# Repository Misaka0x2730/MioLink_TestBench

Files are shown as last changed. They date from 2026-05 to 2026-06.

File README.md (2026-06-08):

# MioLink TestBench

A hardware-in-the-loop bench for automated testing of the
[MioLink](https://github.com/Misaka0x2730/MioLink) debug probe.

The bench builds probe firmware and target test firmware, flashes both onto
real hardware, and runs a suite of functional tests over the physically wired
interfaces (SWD/JTAG, UART, RTT, SWO).

## How it works

A full run consists of three phases orchestrated by [`bench_run_all.sh`](scripts/bench_run_all.sh):

1. **Build probe firmware** ([`miolink_build_all.sh`](scripts/miolink_build_all.sh)) — builds
   every MioLink variant listed in the bench config and stages the `.uf2` images.
2. **Build target firmware** ([`targets_build_all.sh`](scripts/targets_build_all.sh)) —
   builds the `test_board` fixtures for each target platform and CLI backend.
3. **Run tests** ([`bench_run_tests_only.sh`](scripts/bench_run_tests_only.sh)) — flashes the
   probes and targets, verifies probe identity, and runs the tests.

Each script can also be run on its own if you only need a single phase.

## Bench configuration

The physical layout is described by a YAML file under [`config/`](config/): a
flat list of slots where each probe ↔ target pair carries everything needed —
probe serial number, target model, platform, wired interfaces, Vtref mode, SWO
presence, the set of CLI backends, and so on. Every field is documented inline
in the file.

A bench is fully described by its config, so you can keep one per physical setup
and select it with `--config` (the scripts default to
[`config/bench_pizero2w.yaml`](config/bench_pizero2w.yaml)).

## Repository layout

| Directory | Purpose |
|---|---|
| [`firmware/`](firmware/) | Test target firmware (`test_board`); platforms: `stm32f030`, `stm32f103`, `stm32f401`, `hc32f460` |
| [`scripts/cmake/`](scripts/cmake/) | Project-agnostic CMake build driver |
| [`scripts/miolink/`](scripts/miolink/) | Build, flash, and discovery of the MioLink probe (DFU detach / picotool) |
| [`scripts/usbutil/`](scripts/usbutil/) | Generic USB device lookup by VID/PID/serial |
| [`scripts/targets/`](scripts/targets/) | Target firmware builds and target control over GDB/BMP (`gdb`) |
| [`scripts/bench/`](scripts/bench/) | Bench runner and config parser |
| [`scripts/tests/`](scripts/tests/) | Functional tests: `uart`, `rtt`, `swo`, `buffer` |
| [`scripts/runner/`](scripts/runner/) | Self-hosted CI runner provisioning |
| `scripts/*.sh` | Entry-point wrappers from `scripts/`: `bench_run_all`, `bench_run_tests_only`, `miolink_build_all`, `targets_build_all` |
| [`hardware/`](hardware/) | KiCad adapter boards for WeAct Core Boards (STM32F1/F4, MSPM0G3507, STM32G0/C0) |
| [`config/`](config/) | Bench description YAMLs |

## Target platforms

The `test_board` firmware is built for several MCUs that cover different
Cortex-M cores: STM32F030 (CM0), STM32F103 (CM3), STM32F401 (CM4),
HC32F460 (CM4). Variants differ by CLI backend (UART / RTT / disabled),
SWO presence, and build type (Debug / Release).

## Getting started

### Prerequisites

- **ARM GNU Toolchain, CMake, Ninja** — for building the firmware (not needed on
  a bench host that only flashes and tests).
- **Python 3** with the packages from
  [`scripts/requirements.txt`](scripts/requirements.txt) (`pyusb`, `pygdbmi`,
  `pyserial`, `PyYAML`).
- **Git submodules** from [`.gitmodules`](.gitmodules) (CMSIS, STM32 HAL drivers,
  SEGGER RTT, embedded-cli) — pulled in by the clone step below.

### Setup

Clone the repository with its submodules:

```bash
git clone --recurse-submodules https://github.com/Misaka0x2730/MioLink_TestBench.git
cd MioLink_TestBench
```

If you already cloned without `--recurse-submodules`:

```bash
git submodule update --init --recursive
```

Install the Python dependencies:

```bash
pip install -r scripts/requirements.txt
```

## Usage

Run scripts from the repository root.

**Full run** — build probe firmware, build target firmware, flash, and test:

```bash
./scripts/bench_run_all.sh --miolink-firmware-root /path/to/MioLink/firmware
```

**Build only** — skip the flash-and-test phase:

```bash
./scripts/bench_run_all.sh --miolink-firmware-root /path/to/MioLink/firmware --build-only
```

**Run only** — reuse already-built images, just flash and test:

```bash
./scripts/bench_run_all.sh --run-only
```

**Individual phases:**

```bash
# 1. Build the MioLink probe .uf2 images
./scripts/miolink_build_all.sh --miolink-firmware-root /path/to/MioLink/firmware

# 2. Build the test_board target firmware
./scripts/targets_build_all.sh

# 3. Flash everything and run the tests
./scripts/bench_run_tests_only.sh
```

**Useful options** (anything after `--` is forwarded to the bench runner):

```bash
# Run a single probe by serial number
./scripts/bench_run_tests_only.sh -- --probe E66394664F387030

# Include slots marked enabled: false in the config
./scripts/bench_run_tests_only.sh -- --include-disabled

# Skip re-flashing the target firmware
./scripts/bench_run_tests_only.sh -- --no-target-flash

# Use a custom bench config
./scripts/bench_run_all.sh --config config/bench_pizero2w.yaml --miolink-firmware-root /path/to/MioLink/firmware
```

Pass `-h` / `--help` to any script for the full list of flags.

## CI/CD

There are two GitHub Actions workflows: one that purely builds the target
firmware, and one that runs the full hardware-in-the-loop bench.

### Build Test Firmware CI

[`build-test-firmware-ci.yml`](.github/workflows/build-test-firmware-ci.yml)
runs on every push and pull request to `main` (and on manual
`workflow_dispatch`). It compiles the `test_board` firmware for the **full
variant matrix** and packages the results, acting as a compile-only smoke test
that nothing has broken across platforms/configs.

- **`version` job** — derives one version string shared by every artifact name
  (git tag name for tag refs, otherwise the short SHA) so the build matrix and
  the packaging job stay consistent.
- **`build` job (matrix)** — a matrix over the variant axes: target platform,
  `CONFIG_CLI` (`UART` / `RTT` / `NONE`), `CONFIG_TEST_SWO` (`OFF` / `ON`), and
  build type (`Debug` / `Release`). Combinations a platform can't support are
  excluded (e.g. SWO on a Cortex-M0 with no ITM/TPIU). `fail-fast` is off, so one
  broken variant doesn't hide the rest. Each cell checks out submodules, sets up
  the ARM GCC toolchain, extracts any committed vendor SDK the platform needs,
  runs `cmake` configure + build, and uploads a version-stamped `.elf` artifact.
- **`package` job** — runs only if **all** matrix builds succeeded (so the
  archive is never silently incomplete), merges every per-variant ELF into a
  single `MioLink_TestBench_firmware_<version>` archive, and best-effort prunes
  the intermediate `elf-*` staging artifacts.

### Run Bench CI

[`run-bench-ci.yml`](.github/workflows/run-bench-ci.yml) runs the actual bench
on physical hardware. It is triggered by **`repository_dispatch`
(`miolink-build`)** from the MioLink build pipeline once that pipeline has built
the probe firmware — or manually via `workflow_dispatch` with a `run_id` (and an
optional `sha` to report on).

The flow is split so the physical bench host stays cheap (it never compiles):

1. **`build-fixtures` job** (GitHub-hosted) — builds the `test_board` fixtures
   in the exact layout `run_bench.py` expects
   (`firmware/build/cli-X_swo-Y/test_boards/...`) and uploads only the `.elf`
   files as a `target-fixtures` artifact. The self-hosted runner therefore never
   needs a toolchain.
2. **`bench` job** (self-hosted, labels `[self-hosted, miolink-bench]`) — the
   one with the real hardware (e.g. a Pi Zero 2W):
   - Resolves the MioLink `run_id` from the dispatch payload or manual input.
   - **Cross-repo downloads** the exact probe `.uf2` set that this MioLink run
     produced (`actions/download-artifact` with `repository: Misaka0x2730/MioLink`
     + `run-id`, authenticated with the `MIOLINK_BENCH_TOKEN` secret). This
     guarantees the bench tests the precise artifacts that triggered it.
   - Downloads and unpacks the `target-fixtures` from step 1, installs the
     runtime-only Python deps, and runs `scripts/bench_run_tests_only.sh` to
     flash and test against the bench config.
   - A `concurrency` group (`cancel-in-progress: false`) serializes runs so
     concurrent MioLink changes **queue** instead of fighting over the single
     physical bench.
3. **`report` job** — `if: always()`, so it runs even when the bench fails or is
   skipped. It posts a commit status (`context: miolink-bench`) back onto the
   MioLink commit SHA, which renders in MioLink's PR checks list and resolves the
   pending status MioLink had set. It no-ops when there is no SHA to report on
   (e.g. a manual run without the `sha` input).

Both the cross-repo artifact download and the status report authenticate with
the **`MIOLINK_BENCH_TOKEN`** repository secret — a token with read access to
the MioLink repo's Actions artifacts and write access to its commit statuses.
The workflow cannot fetch the probe firmware or report results without it.

In other words, the two repos form a loop: **MioLink builds probe firmware →
dispatches to this repo → the bench flashes and tests it on real targets →
the result is reported back as a check on the MioLink commit.**

### Self-hosted bench runner

The `bench` job lands on a self-hosted runner labelled
`[self-hosted, miolink-bench]` — the host physically wired to the probes and
targets. Because compilation happens on GitHub-hosted runners, this host only
flashes and tests, so a low-powered SBC (e.g. a Raspberry Pi / Pi Zero 2W
running DietPi) is enough.

[`scripts/runner/provision_ghrunner.sh`](scripts/runner/provision_ghrunner.sh)
provisions such a host from scratch. It installs exactly what
`scripts/bench/run_bench.py` needs at job time — `arm-none-eabi-gdb` (flashes
targets over the BMP GDB/MI server), `picotool` (BOOTSEL flashing of RP2 probes,
incl. RP2350 / Pico 2W), `dfu-util` (detaches a running probe into BOOTSEL), and
`python3` + libusb for the runtime deps — plus udev rules and group membership
so an unprivileged service user gets raw-USB and `/dev/ttyACM*` access. It then
registers the GitHub Actions runner under a dedicated `ghrunner` user and
installs it as an auto-starting systemd service.

Run it on the Pi (it re-execs itself with `sudo`):

```bash
sudo ./scripts/runner/provision_ghrunner.sh \
    --toolchain-url <ARM_GNU_TOOLCHAIN_TARBALL_URL> \
    --token         <GITHUB_RUNNER_REGISTRATION_TOKEN> \
    --labels        miolink-bench \
    --url           https://github.com/Misaka0x2730/MioLink_TestBench
```

The `--labels` value must include `miolink-bench` so the `bench` job targets
this host.

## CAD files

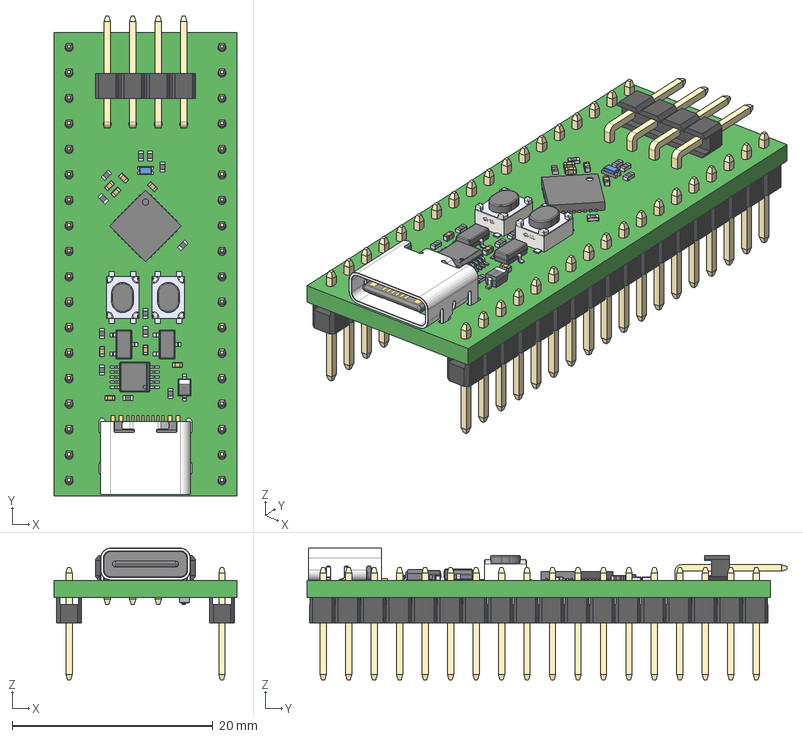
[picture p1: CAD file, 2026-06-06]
hardware/WeAct_MSPM0G3507_CoreBoardAdapter/WeAct-MSPM0G3507SRHBCoreBoard_V10 3D.step
18.2 x 47.8 x 13.1 mm
Leader x 16
Thermal_Shape
SOLID^SW-SMD_4P-L4.2-W3.3-P2.15-LS5.1_SW1_3D_PCB1_2023-06-10(2)_3D_ PCB1_2023-06-10 x 2
R0603
Extruded
Mid_Body x 12
Mark x 12
pin_header_aw140-ea-g04g
pin_header_aw140-eg-g18d x 2
USB_Type-C_A
User Library-SOD323
User Library-led_0603LED0603 blue

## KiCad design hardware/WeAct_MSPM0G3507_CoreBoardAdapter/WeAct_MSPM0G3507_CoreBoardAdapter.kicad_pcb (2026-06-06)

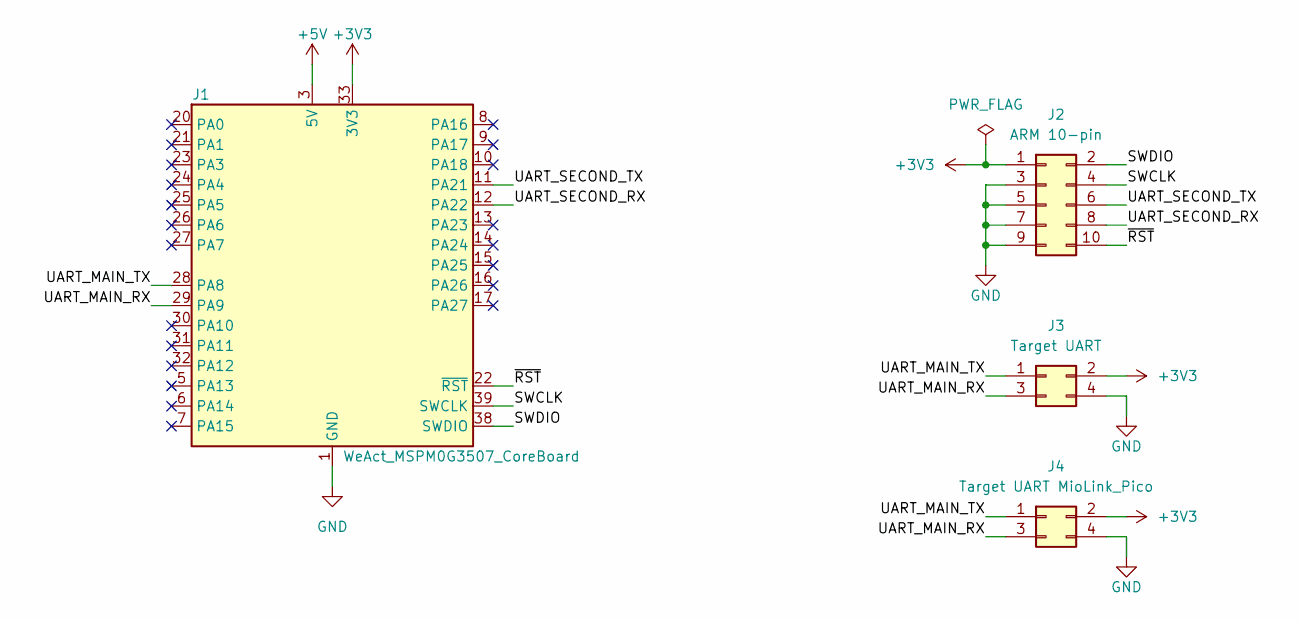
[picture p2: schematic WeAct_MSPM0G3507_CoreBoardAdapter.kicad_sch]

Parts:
J1: WeAct_MSPM0G3507_CoreBoard
J2: ARM 10-pin; PinSocket_2x05_P2.54mm_Horizontal
J3: Target UART; PinSocket_2x02_P2.54mm_Horizontal
J4: Target UART MioLink_Pico; PinSocket_2x02_P2.54mm_Horizontal

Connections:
+3V3: J1.33 (3V3), J1.34 (3V3), J1.37 (3V3), J2.1, J3.2, J4.2
+5V: J1.3 (5V), J1.4 (5V)
/SWCLK: J1.39 (SWCLK), J2.4
/SWDIO: J1.38 (SWDIO), J2.2
/UART_MAIN_RX: J1.29 (PA9), J3.3, J4.3
/UART_MAIN_TX: J1.28 (PA8), J3.1, J4.1
/UART_SECOND_RX: J1.12 (PA22), J2.8
/UART_SECOND_TX: J1.11 (PA21), J2.6
/~RST: J1.22 (~RST), J2.10
GND: J1.1 (GND), J1.2 (GND), J1.18 (GND), J1.19 (GND), J1.35 (GND), J1.36 (GND), J1.40 (GND), J2.3, J2.5, J2.7, J2.9, J3.4, J4.4

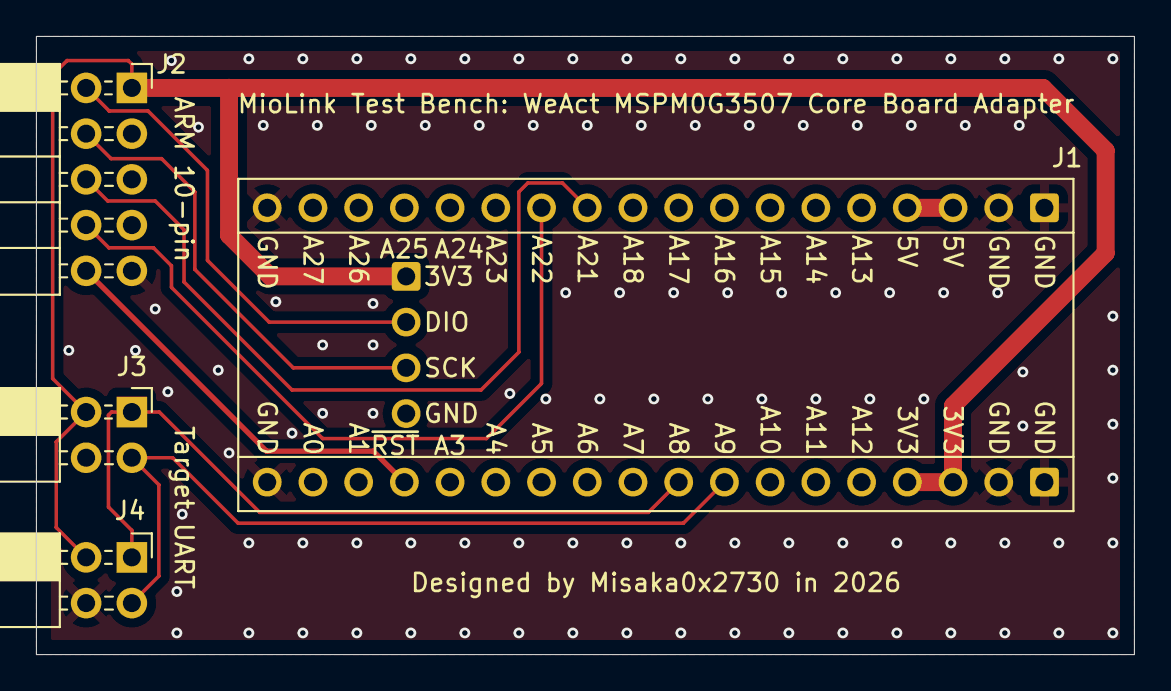
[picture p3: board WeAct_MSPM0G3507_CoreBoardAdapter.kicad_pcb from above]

Board: 2 copper layers, 61.0 x 34.3 mm, 5 parts (1 on the bottom side), 10 nets.

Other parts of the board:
G1: PROJECT PAGE; LOGO

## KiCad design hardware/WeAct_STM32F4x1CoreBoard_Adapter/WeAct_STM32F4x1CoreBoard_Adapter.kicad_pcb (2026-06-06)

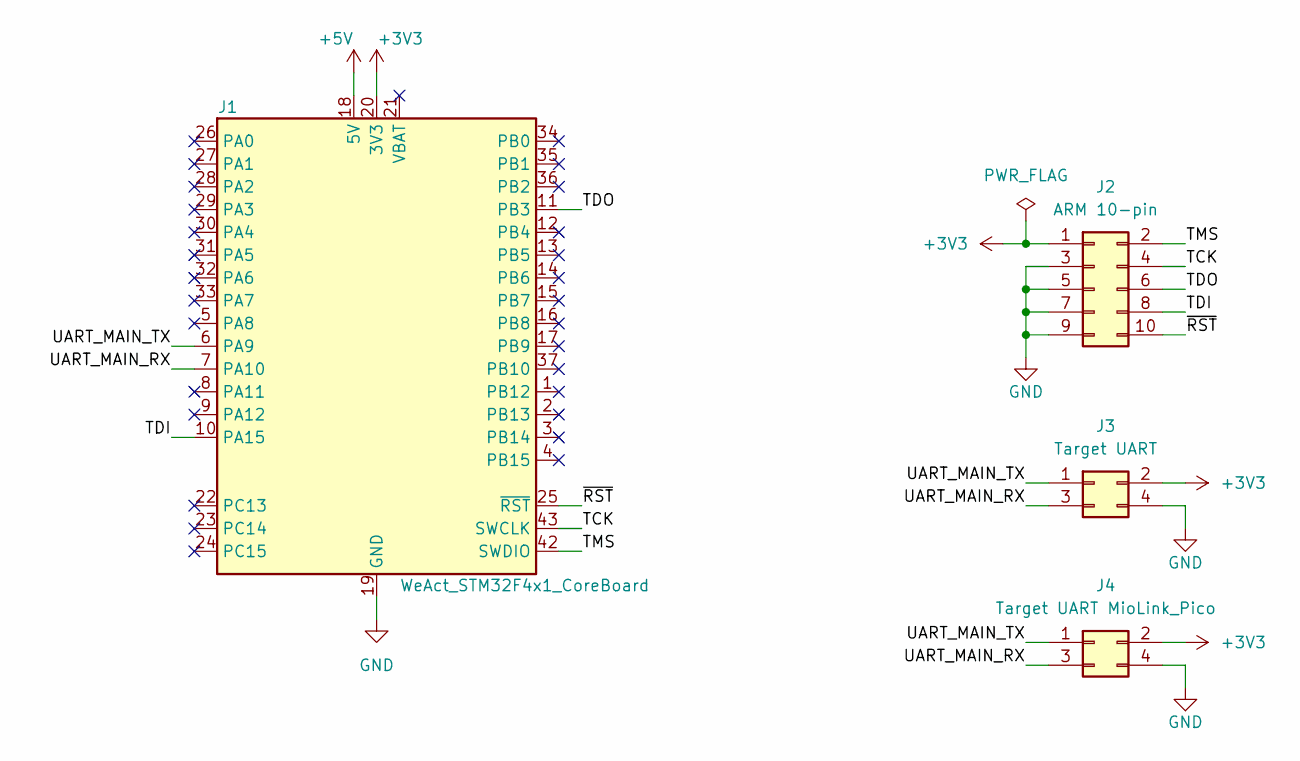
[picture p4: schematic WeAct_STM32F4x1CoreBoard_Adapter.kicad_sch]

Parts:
J1: WeAct_STM32F4x1_CoreBoard
J2: ARM 10-pin; PinSocket_2x05_P2.54mm_Horizontal
J3: Target UART; PinSocket_2x02_P2.54mm_Horizontal
J4: Target UART MioLink_Pico; PinSocket_2x02_P2.54mm_Horizontal

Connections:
+3V3: J1.20 (3V3), J1.38 (3V3), J1.41 (3V3), J2.1, J3.2, J4.2
+5V: J1.18 (5V), J1.40 (5V)
/TCK: J1.43 (SWCLK), J2.4
/TDI: J1.10 (PA15), J2.8
/TDO: J1.11 (PB3), J2.6
/TMS: J1.42 (SWDIO), J2.2
/UART_MAIN_RX: J1.7 (PA10), J3.3, J4.3
/UART_MAIN_TX: J1.6 (PA9), J3.1, J4.1
/~RST: J1.25 (~RST), J2.10
GND: J1.19 (GND), J1.39 (GND), J1.44 (GND), J2.3, J2.5, J2.7, J2.9, J3.4, J4.4

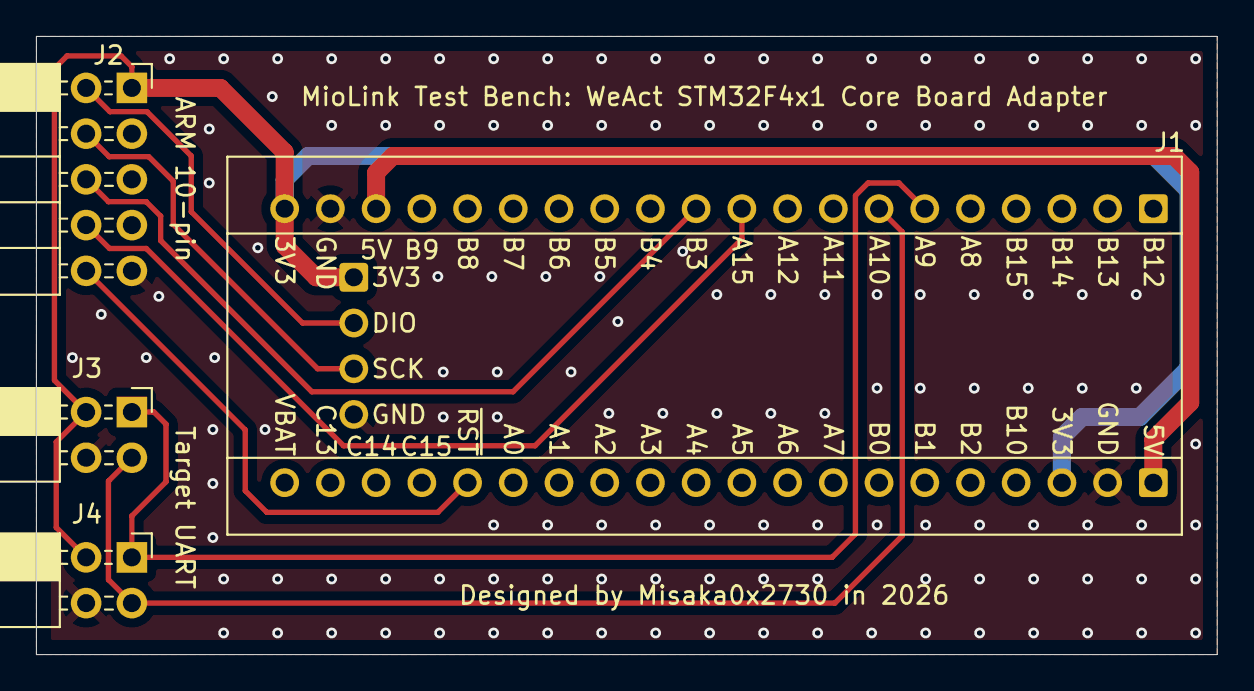
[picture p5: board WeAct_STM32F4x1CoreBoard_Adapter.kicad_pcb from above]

Board: 2 copper layers, 65.6 x 34.3 mm, 5 parts (1 on the bottom side), 10 nets.

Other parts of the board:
G1: PROJECT PAGE; LOGO

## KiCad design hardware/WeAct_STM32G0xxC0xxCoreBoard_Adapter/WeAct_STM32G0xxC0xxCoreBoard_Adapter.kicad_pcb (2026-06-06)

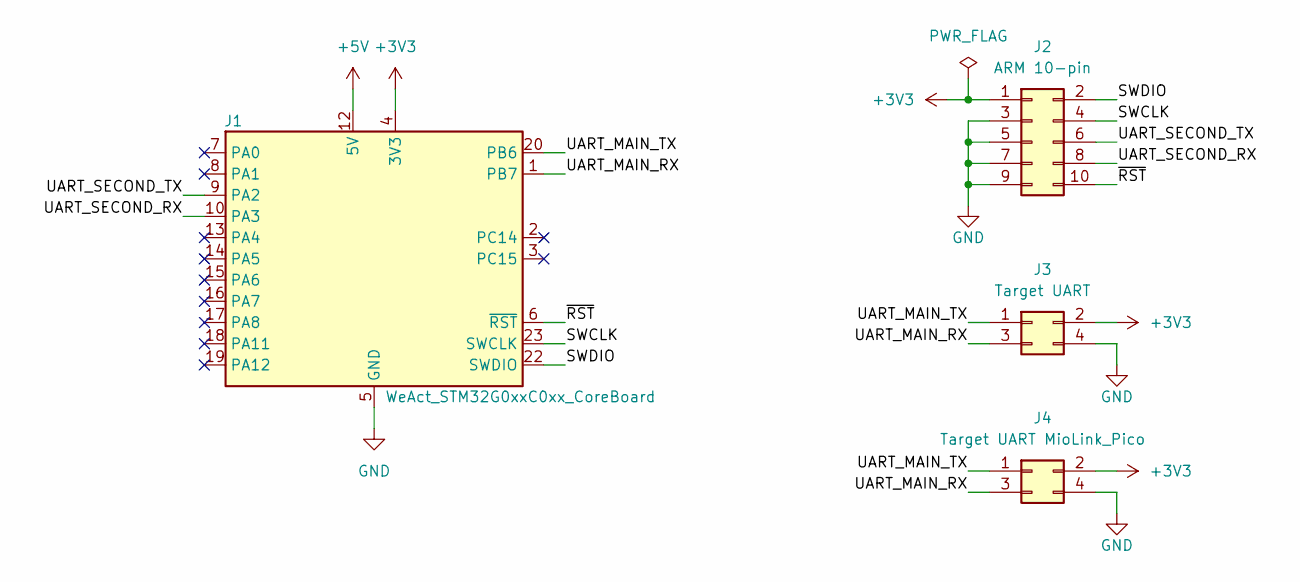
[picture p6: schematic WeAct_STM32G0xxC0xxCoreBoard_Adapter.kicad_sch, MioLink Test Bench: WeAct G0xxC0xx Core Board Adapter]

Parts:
J1: WeAct_STM32G0xxC0xx_CoreBoard
J2: ARM 10-pin; PinSocket_2x05_P2.54mm_Horizontal
J3: Target UART; PinSocket_2x02_P2.54mm_Horizontal
J4: Target UART MioLink_Pico; PinSocket_2x02_P2.54mm_Horizontal

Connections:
+3V3: J1.4 (3V3), J1.21 (3V3), J2.1, J3.2, J4.2
+5V: J1.12 (5V)
/SWCLK: J1.23 (SWCLK), J2.4
/SWDIO: J1.22 (SWDIO), J2.2
/UART_MAIN_RX: J1.1 (PB7), J3.3, J4.3
/UART_MAIN_TX: J1.20 (PB6), J3.1, J4.1
/UART_SECOND_RX: J1.10 (PA3), J2.8
/UART_SECOND_TX: J1.9 (PA2), J2.6
/~RST: J1.6 (~RST), J2.10
GND: J1.5 (GND), J1.11 (GND), J1.24 (GND), J2.3, J2.5, J2.7, J2.9, J3.4, J4.4

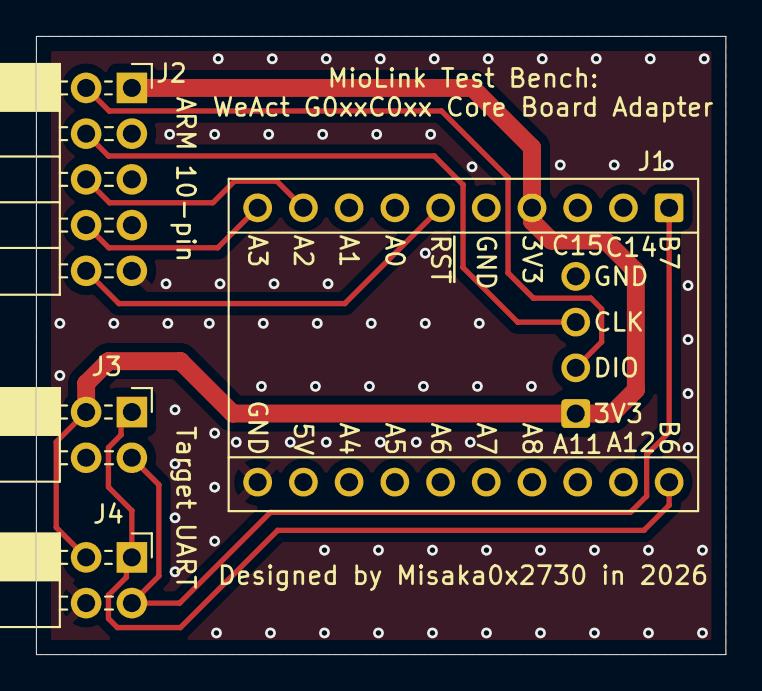
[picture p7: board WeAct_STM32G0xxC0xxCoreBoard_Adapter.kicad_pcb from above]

Board: 2 copper layers, 38.3 x 34.3 mm, 5 parts (1 on the bottom side), 9 nets.

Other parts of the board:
G1: PROJECT PAGE; LOGO

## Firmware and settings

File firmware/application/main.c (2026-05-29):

/**
 * \file   main.c
 * \author Misaka0x2730 (Dmitry Rezvanov)
 * \brief  Main source file
 * \note   This file contains the main entry point for the application.
 */


/**********************************************************************************************************************
 * Includes
 **********************************************************************************************************************/

#include "platform_iface.h"
#include "platform_config.h"

#if (CLI_MODE != CLI_MODE_DISABLED)
#define EMBEDDED_CLI_IMPL
#include "embedded_cli.h"
#endif

#include <stdio.h>
#include <string.h>

#if (CLI_MODE == CLI_MODE_RTT)
#include "SEGGER_RTT.h"
#endif


/**********************************************************************************************************************
 * Private Definitions
 **********************************************************************************************************************/

#define CONFIG_TEST_BUFFER_SIZE (256)

/**********************************************************************************************************************
 * Private Data
 **********************************************************************************************************************/

static uint8_t test_buffer_to_overwrite[CONFIG_TEST_BUFFER_SIZE] = { 0 };
static const char test_string_for_buffer_overwrite[] = "MioLink Testing, platform: " PLATFORM_NAME_STRING "." "Buffer Overwrite Test: Lorem ipsum dolor sit amet, consectetur adipiscing elit.";

static char test_buffer_always_same[CONFIG_TEST_BUFFER_SIZE] __attribute__((used)) =
"Ut enim ad minim veniam, quis nostrud exercitation ullamco laboris nisi ut aliquip ex ea commodo consequat. Duis aute irure dolor in reprehenderit in voluptate velit esse cillum dolore eu fugiat nulla pariatur.";

#if (CONFIG_TEST_SWO_ENABLED == 1)
/**
 * \brief Fixed payload emitted on every SWO test tick so the receiver can verify byte-for-byte stability.
 */
static const char test_swo_message[] =
    "MioLink SWO Test, platform: " PLATFORM_NAME_STRING ", same message every iteration.\r\n";
#endif

#if (CLI_MODE != CLI_MODE_DISABLED)
static EmbeddedCli *cli = NULL;
#endif

/**********************************************************************************************************************
 * Private Function Prototypes
 **********************************************************************************************************************/

#if (CLI_MODE != CLI_MODE_DISABLED)
/**
 * \brief  Function to write a character to the CLI output. This function is used as the writeChar callback for the CLI,
 *         allowing it to send characters to the appropriate output based on the configured CLI mode (RTT or UART).
 *
 * \param[in] embeddedCli Pointer to the EmbeddedCli instance that is writing the character.
 * \param[in] c The character to be written to the CLI output.
 */
static void cli_write_char(EmbeddedCli *embeddedCli, char c);

/**
 * \brief  CLI command handler for the "platform" command. This function is called when the "platform" command is executed
 *         in the CLI. It prints general information about the platform to the CLI output.
 *
 * \param[in] cli Pointer to the EmbeddedCli instance that executed the command.
 * \param[in] args String of arguments passed with the command (not used in this handler).
 * \param[in] context Pointer to any specific context that may be required for this command (not used in this handler).
 */
static void cli_platform_handler(EmbeddedCli *cli, char *args, void *context);

/**
 * \brief  CLI command handler for the "id" command. This function is called when the "id" command is executed in the CLI.
 *         It retrieves and prints the unique identifier of the platform to the CLI output.
 *
 * \param[in] cli Pointer to the EmbeddedCli instance that executed the command.
 * \param[in] args String of arguments passed with the command (not used in this handler).
 * \param[in] context Pointer to any specific context that may be required for this command (not used in this handler).
 */
static void cli_id_handler(EmbeddedCli *cli, char *args, void *context);
#endif

/**
 * \brief  Test function to check for buffer overwriting. It copies a predefined string into a buffer that is intended
 *         to be overwritten, allowing us to verify if the buffer is being overwritten correctly during tests.
 */
static void test_buffer_overwrite(void);

#if (CONFIG_TEST_SWO_ENABLED == 1)
/**
 * \brief  Emits the fixed \c test_swo_message buffer over the SWO line each time the configured period
 *         (\c CONFIG_TEST_SWO_PERIOD_MS) elapses since the previous emission. Called from the main loop and uses
 *         \c platform_get_tick() to compare elapsed time, so it is safe against tick wrap-around.
 */
static void test_swo_periodic(void);
#endif

/**
 * \brief  Function to run various tests in the main loop. This function is called repeatedly in the main loop and can
 *         be used to perform any necessary testing or operations that need to be executed continuously.
 */
static void run_tests(void);

/**********************************************************************************************************************
 * Private Functions
 **********************************************************************************************************************/

#if (CLI_MODE != CLI_MODE_DISABLED)
static void cli_write_char(EmbeddedCli *embeddedCli, char c)
{
#if (CLI_MODE == CLI_MODE_RTT)
    SEGGER_RTT_PutCharSkipNoLock(CONFIG_TEST_RTT_CHANNEL, c);
#elif (CLI_MODE == CLI_MODE_UART)
    platform_cli_uart_transmit((const uint8_t *)&c, 1);
#endif
}

static void cli_platform_handler(EmbeddedCli *cli, char *args, void *context)
{
    embeddedCliPrint(cli, "Platform: " PLATFORM_NAME_STRING);
}

static void cli_id_handler(EmbeddedCli *cli, char *args, void *context)
{
    embeddedCliPrint(cli, platform_get_id());
}
#endif

static void test_buffer_overwrite(void)
{
    memcpy(test_buffer_to_overwrite, test_string_for_buffer_overwrite, sizeof(test_string_for_buffer_overwrite));
}

#if (CONFIG_TEST_SWO_ENABLED == 1)
static void test_swo_periodic(void)
{
    static uint32_t last_tick = 0;
    const uint32_t now = platform_get_tick();

    if ((uint32_t)(now - last_tick) >= (uint32_t)CONFIG_TEST_SWO_PERIOD_MS)
    {
        last_tick = now;
        platform_swo_send((const uint8_t *)test_swo_message, (uint16_t)(sizeof(test_swo_message) - 1U));
    }
}
#endif

static void run_tests(void)
{
    volatile char dummy = test_buffer_always_same[0]; // prevent optimization of test_buffer_always_same
    (void)dummy; // prevent unused variable warning

    test_buffer_overwrite();
#if (CONFIG_TEST_SWO_ENABLED == 1)
    test_swo_periodic();
#endif
}

/**********************************************************************************************************************
 * Public Functions
 **********************************************************************************************************************/

#if (CLI_MODE == CLI_MODE_UART)
void cli_rx_callback(const uint8_t data)
{
    if (cli != NULL)
    {
        embeddedCliReceiveChar(cli, data);
    }
}
#endif

int main(void)
{
    platform_init();

#if (CONFIG_TEST_SWO_ENABLED == 1)
    platform_swo_init(CONFIG_TEST_SWO_BAUDRATE);
#endif

#if (CLI_MODE == CLI_MODE_RTT)
    SEGGER_RTT_Init();
#elif (CLI_MODE == CLI_MODE_UART)
    platform_cli_uart_init(CONFIG_TEST_UART_BAUDRATE);
#endif

#if (CLI_MODE != CLI_MODE_DISABLED)
    EmbeddedCliConfig cli_config = { 0 };
    memcpy(&cli_config, embeddedCliDefaultConfig(), sizeof(cli_config));
    cli_config.enableAutoComplete = false; // disable autocompletion to simplify testing

    cli = embeddedCliNew(&cli_config);

    if (cli == NULL)
    {
        while (1);
    }
    cli->writeChar = cli_write_char;

    CliCommandBinding id_binding = {"id", "Print unique platform ID", 0, NULL, cli_id_handler};
    CliCommandBinding platform_binding = {"platform", "Print general platform info", 0, NULL, cli_platform_handler};

    embeddedCliAddBinding(cli, id_binding);
    embeddedCliAddBinding(cli, platform_binding);
#endif

    while (1)
    {
        run_tests();
#if (CLI_MODE != CLI_MODE_DISABLED)
        embeddedCliProcess(cli);
#endif
    }

    return 0;
}

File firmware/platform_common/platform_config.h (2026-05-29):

/**
 * \file   platform_config.h
 * \author Misaka0x2730 (Dmitry Rezvanov)
 * \brief  Platform configuration header file
 * \note   This file defines the configuration options for platform-specific implementations.
 */

#ifndef PLATFORM_CONFIG_H_
#define PLATFORM_CONFIG_H_

/**********************************************************************************************************************
 * Includes
 **********************************************************************************************************************/

// System
#include <stdint.h>

/**********************************************************************************************************************
 * Public Definitions
 **********************************************************************************************************************/

#define CLI_MODE_DISABLED 0
#define CLI_MODE_RTT      1
#define CLI_MODE_UART     2

#if (defined(CONFIG_CLI_USE_RTT) + defined(CONFIG_CLI_USE_UART) + defined(CONFIG_CLI_DISABLED)) > 1
#error "Multiple CLI modes defined. Please define only one of CONFIG_CLI_USE_RTT, CONFIG_CLI_USE_UART, or CONFIG_CLI_DISABLED."
#endif

#if !defined(CONFIG_CLI_USE_RTT) && !defined(CONFIG_CLI_USE_UART) && !defined(CONFIG_CLI_DISABLED)
#error "No CLI mode defined. Please define CONFIG_CLI_USE_RTT, CONFIG_CLI_USE_UART, or CONFIG_CLI_DISABLED."
#endif

#if defined(CONFIG_CLI_DISABLED)
#define CLI_MODE CLI_MODE_DISABLED
#elif defined(CONFIG_CLI_USE_RTT)
#define CLI_MODE CLI_MODE_RTT
#elif defined(CONFIG_CLI_USE_UART)
#define CLI_MODE CLI_MODE_UART
#endif

#if (CLI_MODE == CLI_MODE_RTT) && (!defined(CONFIG_TEST_RTT_CHANNEL))
#define CONFIG_TEST_RTT_CHANNEL 0
#endif

#if (CLI_MODE == CLI_MODE_UART) && (!defined(CONFIG_TEST_UART_BAUDRATE))
#define CONFIG_TEST_UART_BAUDRATE 115200
#endif

#if !defined(CONFIG_TEST_SWO_ENABLED)
#define CONFIG_TEST_SWO_ENABLED 0
#endif

#if !defined(CONFIG_TEST_SWO_BAUDRATE)
#define CONFIG_TEST_SWO_BAUDRATE 2250000
#endif

#if !defined(CONFIG_TEST_SWO_PERIOD_MS)
#define CONFIG_TEST_SWO_PERIOD_MS 1000
#endif


#endif // PLATFORM_CONFIG_H_

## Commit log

2026-03-17 Initial commit, added stm32f103 and stm32f401 test platforms
2026-05-29 Implemented test scripts, added STM32F030 and HC32F460 platforms
2026-06-01 Fixed problem with wrong RP2350 PID
2026-06-06 Added KiCad files for adapter boards for MSPM0G3507, STM32F103, STM32F411 and STM32G030_F030
    [WeAct-MSPM0G3507SRHBCoreBoard_V10 3D.step, WeAct_MSPM0G3507_CoreBoardAdapter.kicad_pcb, WeAct_MSPM0G3507_CoreBoardAdapter.kicad_sch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]

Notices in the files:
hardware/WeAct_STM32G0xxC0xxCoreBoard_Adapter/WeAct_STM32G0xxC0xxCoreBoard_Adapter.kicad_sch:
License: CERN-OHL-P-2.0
